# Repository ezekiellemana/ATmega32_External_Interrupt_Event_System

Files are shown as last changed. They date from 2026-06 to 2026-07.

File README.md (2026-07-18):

# ATmega32 External Interrupt Event Counter System

## CT 321 PBL 07 - External Interrupt-Based Emergency Stop and Event Counter System

This repository contains the completed ATmega32 external interrupt emergency stop and event counter system. The project demonstrates event-driven embedded-system control using INT0, INT1, and INT2. The design was verified using SimulIDE, KiCad, MPLAB for VS Code / AVR-GCC compatible firmware, Gerber export, and a recorded demonstration video.

---

## Final Submission Status

| Requirement | Evidence / Location | Status |
| --- | --- | --- |
| System block diagram | `documentation/block_diagram.png` | Complete |
| ATmega32 pin mapping table | `documentation/pin_mapping_table.md` | Complete |
| Firmware flowchart | `documentation/flowchart.png` | Complete |
| KiCad schematic | `kicad/schematic/kicad_schematic.png`, `.pdf`, and `kicad/ATmega32_External_Interrupt_Event_System.kicad_sch` | Complete |
| KiCad PCB layout | `kicad/pcb/kicad_pcb.png` and `kicad/ATmega32_External_Interrupt_Event_System.kicad_pcb` | Complete |
| KiCad PCB 3D view | `kicad/pcb/kicad_pcb_3D.png`, `kicad/pcb/kicad_pcb_3D_2.png` | Complete |
| DRC result | `kicad/pcb/drc_zero_errors.png` | Complete - 0 violations / 0 unconnected items |
| Gerber and drill files | `kicad/gerber/` | Complete |
| Firmware source code | `firmware/src/main.c` | Complete |
| Compiled HEX file | `firmware/hex/emergency_event_counter.hex` | Complete |
| SimulIDE circuit | `simulide/circuit/emergency_event_counter.sim1` | Complete |
| SimulIDE screenshots | `simulide/screenshots/` | Complete - 7 tests captured |
| Test results table | `documentation/test_results.md` | Complete |
| Final report DOCX | `documentation/final_report/CT_321_PBL_07_Group07_Final_Report.docx` | Complete |
| Final report PDF | `documentation/final_report/CT_321_PBL_07_Group07_Final_Report.pdf` | Complete |
| PowerPoint presentation | `documentation/CT_321_PBL_07_Group07_Presentation.pptx` | Complete |
| Demonstration video | `media/demo_video.mp4` | Complete |

---

## Circuit and PCB Images

### Schematic

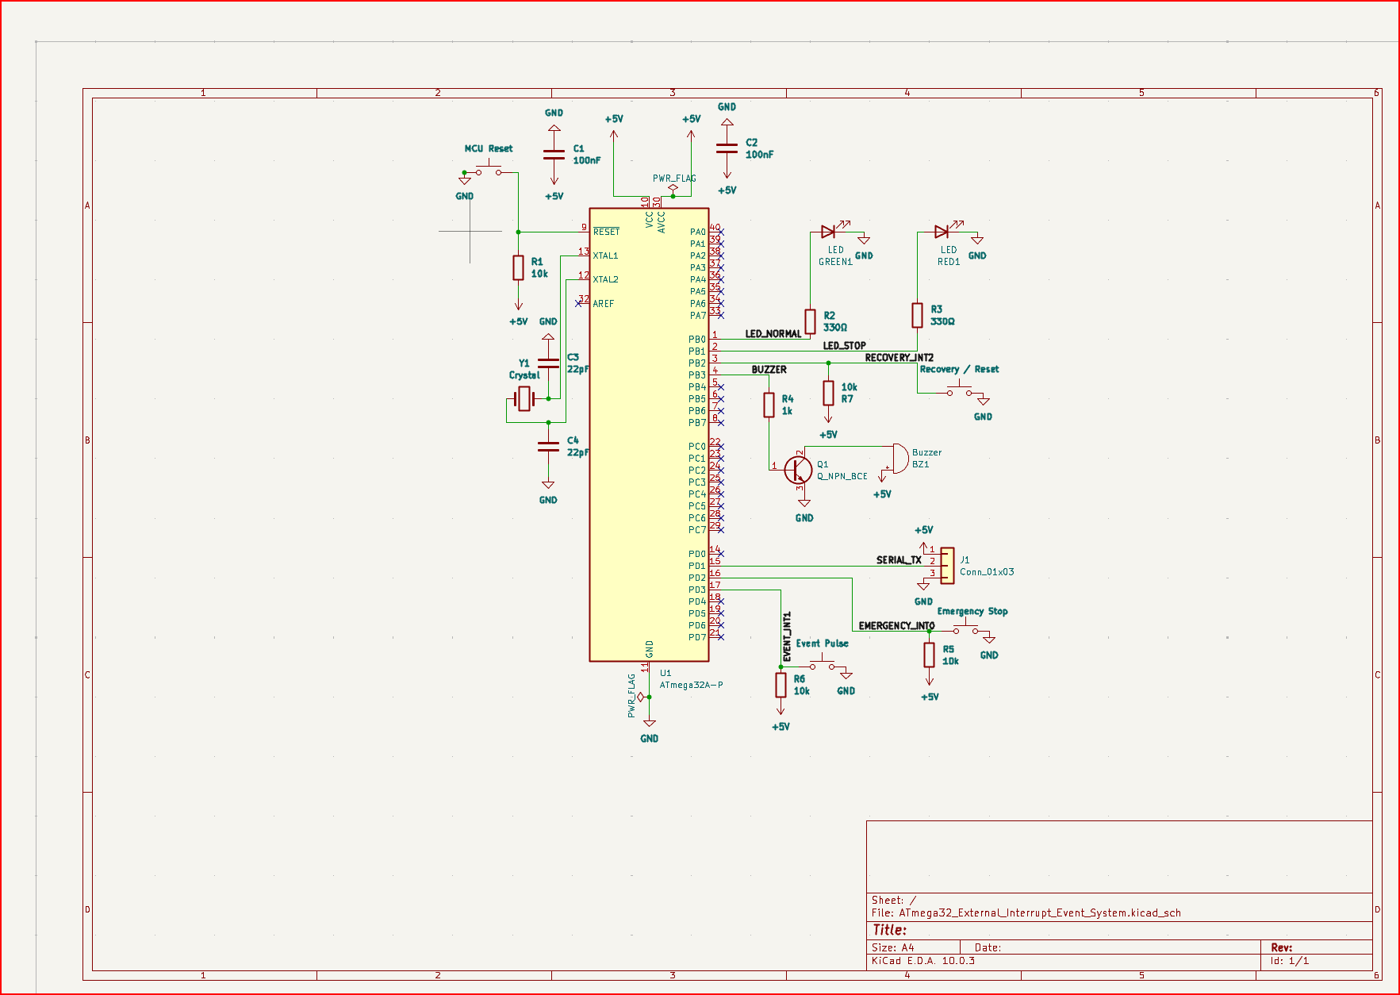
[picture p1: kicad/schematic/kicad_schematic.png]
KiCad schematic


### PCB Layout (2D)

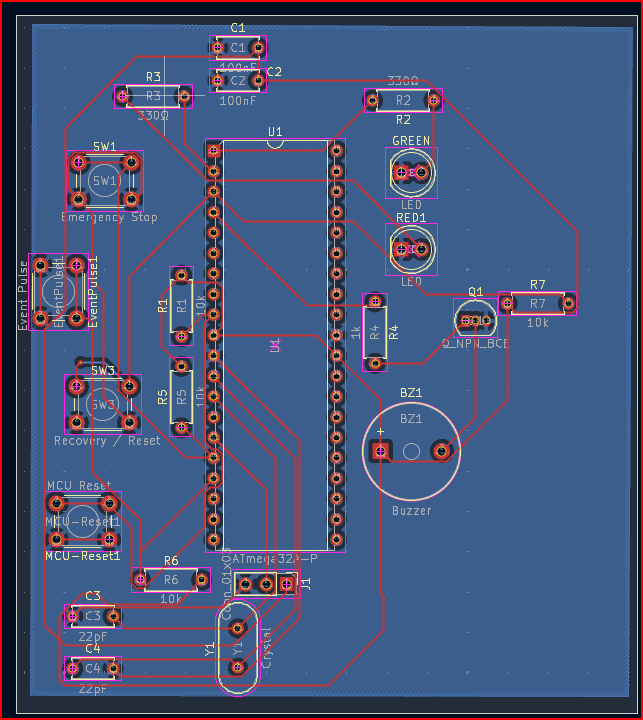
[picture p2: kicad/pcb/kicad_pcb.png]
KiCad PCB layout


### PCB 3D View

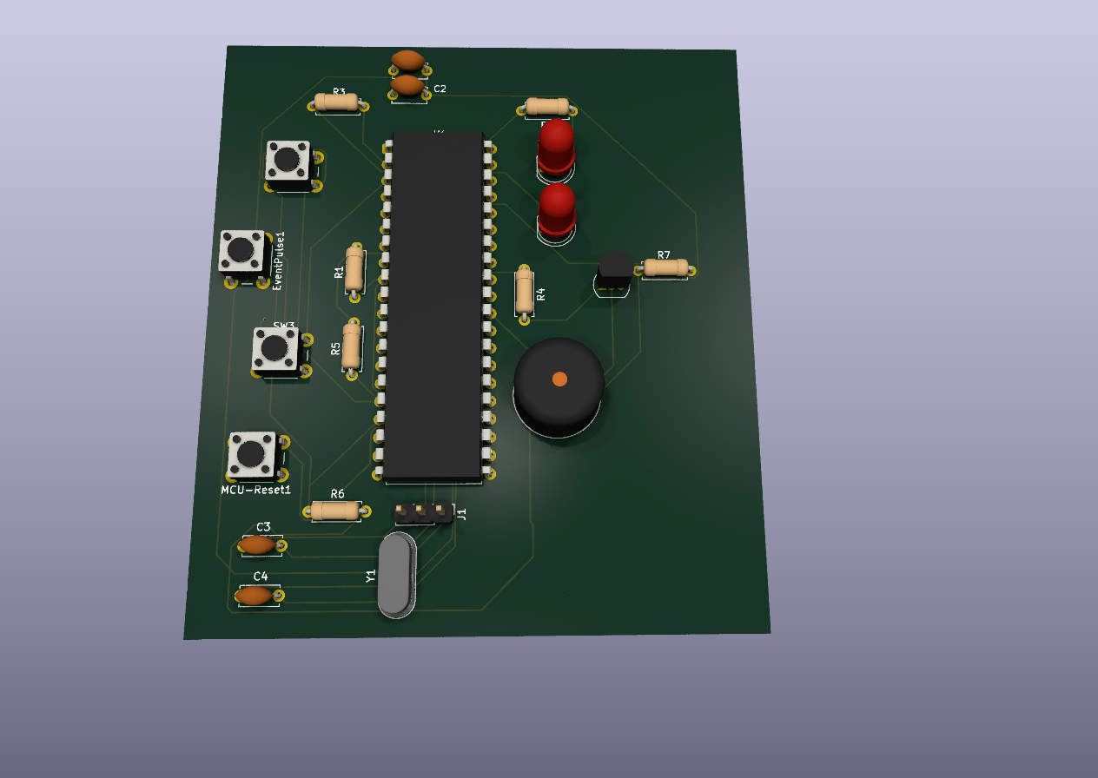
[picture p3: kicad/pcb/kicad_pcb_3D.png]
KiCad PCB 3D view


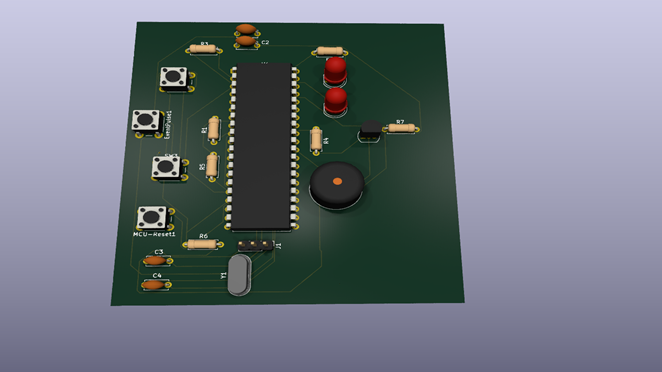
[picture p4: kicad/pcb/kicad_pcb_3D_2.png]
KiCad PCB 3D view - alternate angle


---

## System Behaviour

| Action | Expected Result |
| --- | --- |
| System powered ON | Green LED ON, red LED OFF, buzzer OFF, serial count = 0 |
| Event pulse on INT1 | Event count increases only in normal mode |
| Emergency stop on INT0 | Red LED and buzzer ON, green LED OFF, counting stops |
| Event during emergency | Count does not increase |
| Recovery on INT2 during emergency | System returns to normal mode and keeps the current count |
| Recovery/reset on INT2 during normal mode | Event count resets to zero |

---

## Important Simulation Settings

```text
MCU: ATmega32 / ATmega32A
Clock: 8 MHz
HEX file: firmware/hex/emergency_event_counter.hex
UART: 9600 baud, 8 data bits, 1 stop bit
Inputs: active LOW buttons with pull-ups
RESET: held HIGH during normal running
```

---

## Folder Structure

```text
ATmega32_External_Interrupt_Event_System/
|-- README.md
|-- firmware/
|   |-- src/main.c
|   |-- include/
|   `-- hex/emergency_event_counter.hex
|-- kicad/
|   |-- ATmega32_External_Interrupt_Event_System.kicad_pro
|   |-- ATmega32_External_Interrupt_Event_System.kicad_sch
|   |-- ATmega32_External_Interrupt_Event_System.kicad_pcb
|   |-- schematic/
|   |-- pcb/
|   `-- gerber/
|-- simulide/
|   |-- circuit/emergency_event_counter.sim1
|   `-- screenshots/
|-- documentation/
|   |-- CT_321_PBL_07_Group07_Presentation.pptx
|   |-- block_diagram.png
|   |-- flowchart.png
|   |-- interrupt_configuration.md
|   |-- pin_mapping_table.md
|   |-- test_results.md
|   `-- final_report/
|       |-- CT_321_PBL_07_Group07_Final_Report.docx
|       `-- CT_321_PBL_07_Group07_Final_Report.pdf
`-- media/
    |-- demo_video.mp4
    `-- demonstration_video_link.txt
```

---

## Demonstration Summary

The final simulation and video demonstrate normal startup, single event counting, multiple event counting, emergency stop, lockout of event counting during emergency mode, recovery back to normal mode, and reset of the count in normal mode.

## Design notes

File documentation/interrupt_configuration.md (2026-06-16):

# Interrupt Configuration

## Button Wiring — Active-LOW Inputs

The emergency, event, and recovery/reset buttons are wired as active-LOW inputs. Each button connects the microcontroller input pin to GND when pressed.

When the button is not pressed, the input pin is held HIGH. When the button is pressed, the input pin goes LOW. This HIGH-to-LOW transition creates the falling edge used to trigger the external interrupt.

The firmware enables the ATmega32 internal pull-up resistors. The KiCad schematic and PCB also include external 10 kΩ pull-up resistors for the interrupt inputs. This is acceptable because the external pull-ups reinforce the HIGH level and make the schematic clear for the assignment.

---

## Interrupt Inputs

| Interrupt | MCU Pin | Net Label | Button | Pull-up |
| --- | --- | --- | --- | --- |
| INT0 | PD2 / DIP pin 16 | `EMERGENCY_INT0` | Emergency stop | 10 kΩ to +5V plus internal pull-up |
| INT1 | PD3 / DIP pin 17 | `EVENT_INT1` | Event pulse | 10 kΩ to +5V plus internal pull-up |
| INT2 | PB2 / DIP pin 3 | `RECOVERY_INT2` | Recovery/reset | 10 kΩ to +5V plus internal pull-up |

---

## Falling-Edge Trigger Configuration

### INT0 — Emergency Stop

INT0 uses PD2 and is configured for falling edge triggering.

```c
MCUCR |=  (1 << ISC01);
MCUCR &= ~(1 << ISC00);
```

### INT1 — Event Pulse

INT1 uses PD3 and is also configured for falling edge triggering.

```c
MCUCR |=  (1 << ISC11);
MCUCR &= ~(1 << ISC10);
```

### INT2 — Recovery / Reset

INT2 uses PB2. On ATmega32, INT2 uses the ISC2 bit in MCUCSR. Clearing ISC2 selects falling edge triggering.

```c
MCUCSR &= ~(1 << ISC2);
```

All interrupts are enabled through GICR:

```c
GICR |= (1 << INT0) | (1 << INT1) | (1 << INT2);
```

---

## ISR Behaviour

| Interrupt | Trigger | Firmware action |
| --- | --- | --- |
| INT0 emergency | Emergency button pressed | Sets `emergency_mode = 1`; red LED and buzzer turn ON; counting is locked |
| INT1 event | Event button/sensor pulse | Increments `event_count` only if `emergency_mode == 0` |
| INT2 recovery/reset | Recovery button pressed | If in emergency mode, returns to normal; if already normal, resets count to 0 |

---

## Debounce Logic

Mechanical push buttons can bounce and create several fast transitions during one press. The firmware prevents false multiple counts using a Timer0 millisecond tick and a 200 ms debounce window.

Timer0 creates a 1 ms system tick:

```text
Clock: 8 MHz
Prescaler: 64
OCR0: 124
Tick: 1 ms
```

Each external interrupt has its own last-accepted timestamp. An interrupt is accepted only when at least 200 ms has passed since the previous accepted interrupt on the same line.

```c
if ((now - last_int0_ms) >= DEBOUNCE_MS) {
    last_int0_ms = now;
    emergency_mode = 1;
}
```

This prevents button bounce from producing multiple counts or repeated emergency/recovery actions.

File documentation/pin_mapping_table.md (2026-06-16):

# ATmega32 Pin Mapping Table

| ATmega32 Pin | DIP-40 Pin # | Direction | Net Label | Connected Device | Notes |
| --- | --- | --- | --- | --- | --- |
| PB0 | 1 | Output | `LED_NORMAL` | R2 330 Ω → Green LED → GND | HIGH = normal LED ON |
| PB1 | 2 | Output | `LED_STOP` | R3 330 Ω → Red LED → GND | HIGH = stop LED ON |
| PB2 / INT2 | 3 | Input | `RECOVERY_INT2` | SW3 → GND, R7 10 kΩ → +5V | Recovery/reset interrupt |
| PB3 | 4 | Output | `BUZZER` | R4 1 kΩ → Q1 base → BZ1 driver | HIGH = buzzer ON |
| RESET | 9 | Input | `RESET` | R1 10 kΩ → +5V, reset button → GND | Active-LOW MCU reset |
| VCC | 10 | Power | `+5V` | +5V zone, C1 100 nF to GND | Digital supply |
| GND | 11 | Power | `GND` | GND zone | Ground |
| XTAL1 | 13 | Input | `XTAL1` | Y1 8 MHz crystal, C3 22 pF to GND | Clock input |
| XTAL2 | 14 | Output | `XTAL2` | Y1 8 MHz crystal, C4 22 pF to GND | Clock output |
| PD1 / TXD | 15 | Output | `SERIAL_TX` | J1 pin 2 | UART transmit, 9600 baud |
| PD2 / INT0 | 16 | Input | `EMERGENCY_INT0` | SW1 → GND, R5 10 kΩ → +5V | Emergency stop interrupt |
| PD3 / INT1 | 17 | Input | `EVENT_INT1` | SW2 → GND, R6 10 kΩ → +5V | Event pulse interrupt |
| AVCC | 30 | Power | `+5V` | +5V zone, C2 100 nF to GND | Must be tied to VCC |
| GND | 31 | Power | `GND` | GND zone | Ground |

## Unused Pins

The remaining ATmega32 pins are not used in this project. They are marked as no-connect in the schematic where appropriate.

## Power Notes

- VCC and AVCC are both connected to +5V.
- Both GND pins are connected to the GND zone.
- C1 and C2 are 100 nF decoupling capacitors.
- A B.Cu copper zone is used for GND.
- An F.Cu copper zone is used for +5V.

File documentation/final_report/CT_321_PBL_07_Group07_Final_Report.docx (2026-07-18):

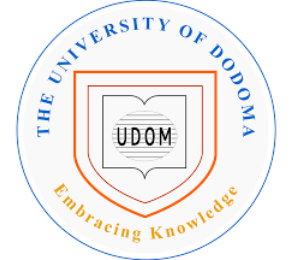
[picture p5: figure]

THE UNIVERSITY OF DODOMA

COLLEGE OF INFORMATICS AND VIRTUAL EDUCATION

DEPARTMENT OF COMPUTER SCIENCE AND ENGINEERING

GROUP ASSIGNMENT REPORT

GROUP NUMBER: 07
MODULE NAME: MICROCONTROLLER SYSTEMS
MODULE CODE: CT 321
SEMESTER: TWO
ACADEMIC YEAR: 2025 / 2026

PBL TITLE: EXTERNAL INTERRUPT-BASED EMERGENCY STOP AND EVENT COUNTER SYSTEM

PARTICIPANTS

S/N | NAME | REG NUMBER | PROGRAMME
1 | EZEKIEL LEMANA | T23-03-00241 | CE3
2 | HARUN KADILO | T23-03-01251 | CE3
3 | JACKSON MANDA | T23-03-18278 | CE3
4 | YASSIN JABIR | T23-03-14605 | CE3

# 1. Introduction

Many embedded systems must react immediately to external events such as emergency stop buttons, object detection sensors, alarms, or motion triggers. A polling-based program may miss short input pulses if the processor is busy with another task. External interrupts solve this problem by allowing the microcontroller to stop normal execution temporarily and run a service routine when an important event occurs.

This project demonstrates how ATmega32 external interrupts can be used to build a safe event-driven system. The system counts external event pulses in normal mode, enters emergency-stop mode when the emergency button is pressed, prevents counting during emergency mode, and returns to normal operation using a recovery/reset button.

# 2. Problem Statement and Objectives

The problem is to design a controller that can count normal events while still responding immediately to an emergency condition. The emergency input must dominate the normal counting operation so that the system stops counting and activates alarm indicators without delay.

## 2.1 Objectives

- To design an ATmega32-based event counter using external interrupts.
- To implement immediate emergency-stop response using INT0.
- To count event pulses during normal mode using INT1.
- To recover from emergency mode and reset the count using INT2.
- To indicate system state using green LED, red LED, buzzer, and UART serial output.
- To design the schematic and PCB layout in KiCad and generate Gerber files.
- To verify the system using SimulIDE screenshots and a demonstration video.

# 3. Expected System Operation

Input / Event | Expected Response
System powered ON | Green LED ON, red LED OFF, buzzer OFF, serial shows NORMAL mode with count 0.
Object/event pulse detected | Event count increases only when the system is in normal mode.
Emergency stop button pressed | System enters EMERGENCY STOP mode; red LED and buzzer turn ON; counting stops.
Event pulse during emergency | Event count does not increase.
Recovery button pressed during emergency | System returns to NORMAL mode and keeps the current count.
Recovery/reset button pressed in normal mode | Event count resets to zero.

# 4. System Design

## 4.1 System Block Diagram

The block diagram shows the external interrupt inputs, ATmega32 controller, output indicators, buzzer, serial terminal, and 5 V power supply used in the system.

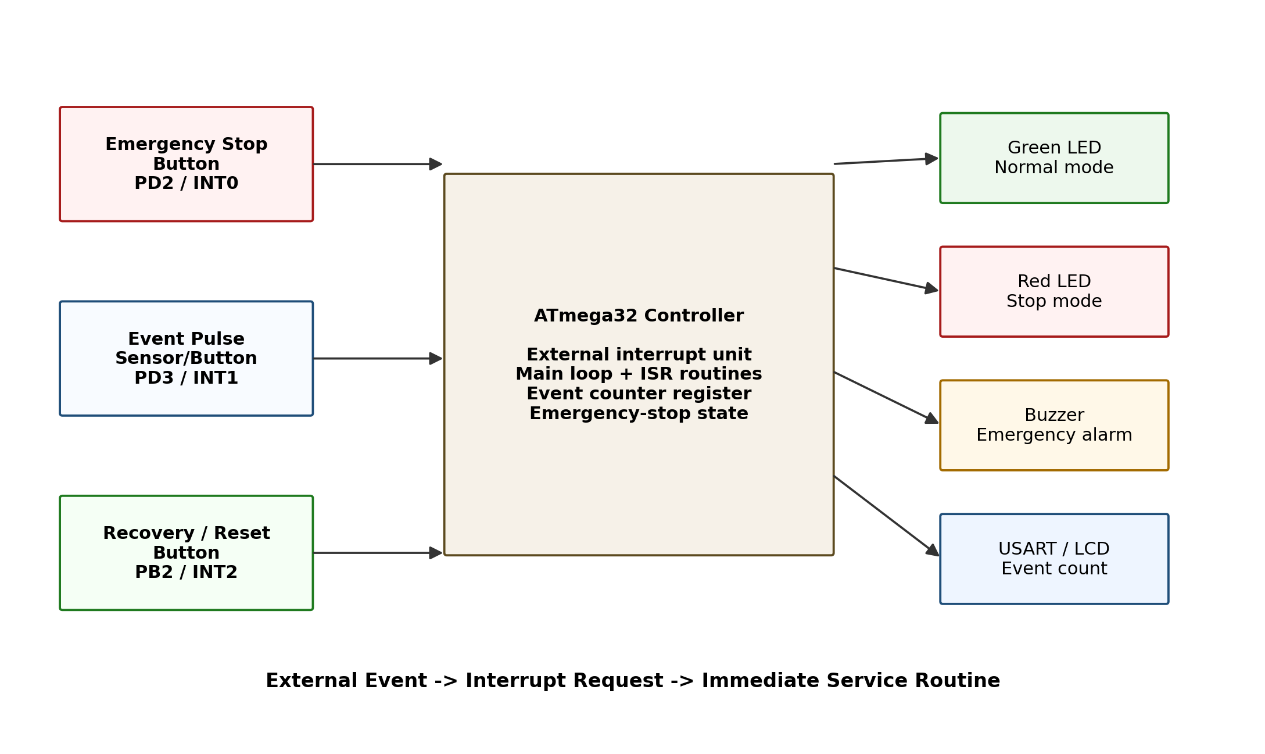
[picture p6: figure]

Figure 1: System block diagram.

## 4.2 Components Used

Component | Quantity | Purpose
ATmega32 / ATmega32A | 1 | Main microcontroller and interrupt controller.
Emergency stop push button | 1 | Triggers INT0 and starts emergency mode.
Event pulse button / sensor | 1 | Triggers INT1 and increments the event count.
Recovery/reset push button | 1 | Triggers INT2; recovers from emergency or resets count.
MCU reset button | 1 | Hardware reset for the ATmega32.
Green LED | 1 | Normal mode indicator.
Red LED | 1 | Emergency stop indicator.
Active buzzer | 1 | Emergency alarm output.
NPN transistor and 1 kOhm resistor | 1 set | Buzzer driver stage.
330 Ohm resistors | 2 | LED current limiting.
10 kOhm resistors | 4 | RESET and interrupt input pull-up resistors.
8 MHz crystal and 22 pF capacitors | 1 set | External clock circuit.
100 nF capacitors | 2 | VCC and AVCC decoupling.
3-pin serial header | 1 | +5V, serial TX, and GND connection.

## 4.3 ATmega32 Pin Mapping

ATmega32 Pin | DIP Pin | Direction | Net / Function | Connected Device
PB0 | 1 | Output | LED_NORMAL | R2 330 Ohm -> Green LED -> GND
PB1 | 2 | Output | LED_STOP | R3 330 Ohm -> Red LED -> GND
PB2 / INT2 | 3 | Input | RECOVERY_INT2 | SW3 -> GND, R7 10 kOhm -> +5V
PB3 | 4 | Output | BUZZER | R4 1 kOhm -> Q1 base -> Buzzer driver
RESET | 9 | Input | RESET | R1 10 kOhm -> +5V, reset button -> GND
VCC | 10 | Power | +5V | Digital supply and decoupling
GND | 11 | Power | GND | Ground zone
XTAL1 | 13 | Input | XTAL1 | 8 MHz crystal and C3 22 pF
XTAL2 | 14 | Output | XTAL2 | 8 MHz crystal and C4 22 pF
PD1 / TXD | 15 | Output | SERIAL_TX | J1 pin 2, UART 9600 baud
PD2 / INT0 | 16 | Input | EMERGENCY_INT0 | SW1 -> GND, R5 10 kOhm -> +5V
PD3 / INT1 | 17 | Input | EVENT_INT1 | SW2 -> GND, R6 10 kOhm -> +5V
AVCC | 30 | Power | +5V | Analog/digital supply and decoupling
GND | 31 | Power | GND | Ground zone

# 5. Interrupt and Firmware Design

## 5.1 Interrupt Configuration

The input buttons are wired as active-LOW inputs. The inputs are normally HIGH through pull-up resistors and become LOW when a button is pressed. Therefore, falling-edge triggering is used for INT0, INT1, and INT2.

Interrupt | MCU Pin | Trigger | Firmware Action
INT0 | PD2 | Falling edge | Set emergency_mode = 1; red LED and buzzer ON; counting locked.
INT1 | PD3 | Falling edge | Increment event_count only if emergency_mode == 0.
INT2 | PB2 | Falling edge | If emergency, recover to normal; if normal, reset count to 0.

## 5.2 Firmware Flowchart

The firmware initializes GPIO, UART, Timer0, and the three external interrupts. The main loop updates outputs and serial messages, while the ISRs handle urgent events.

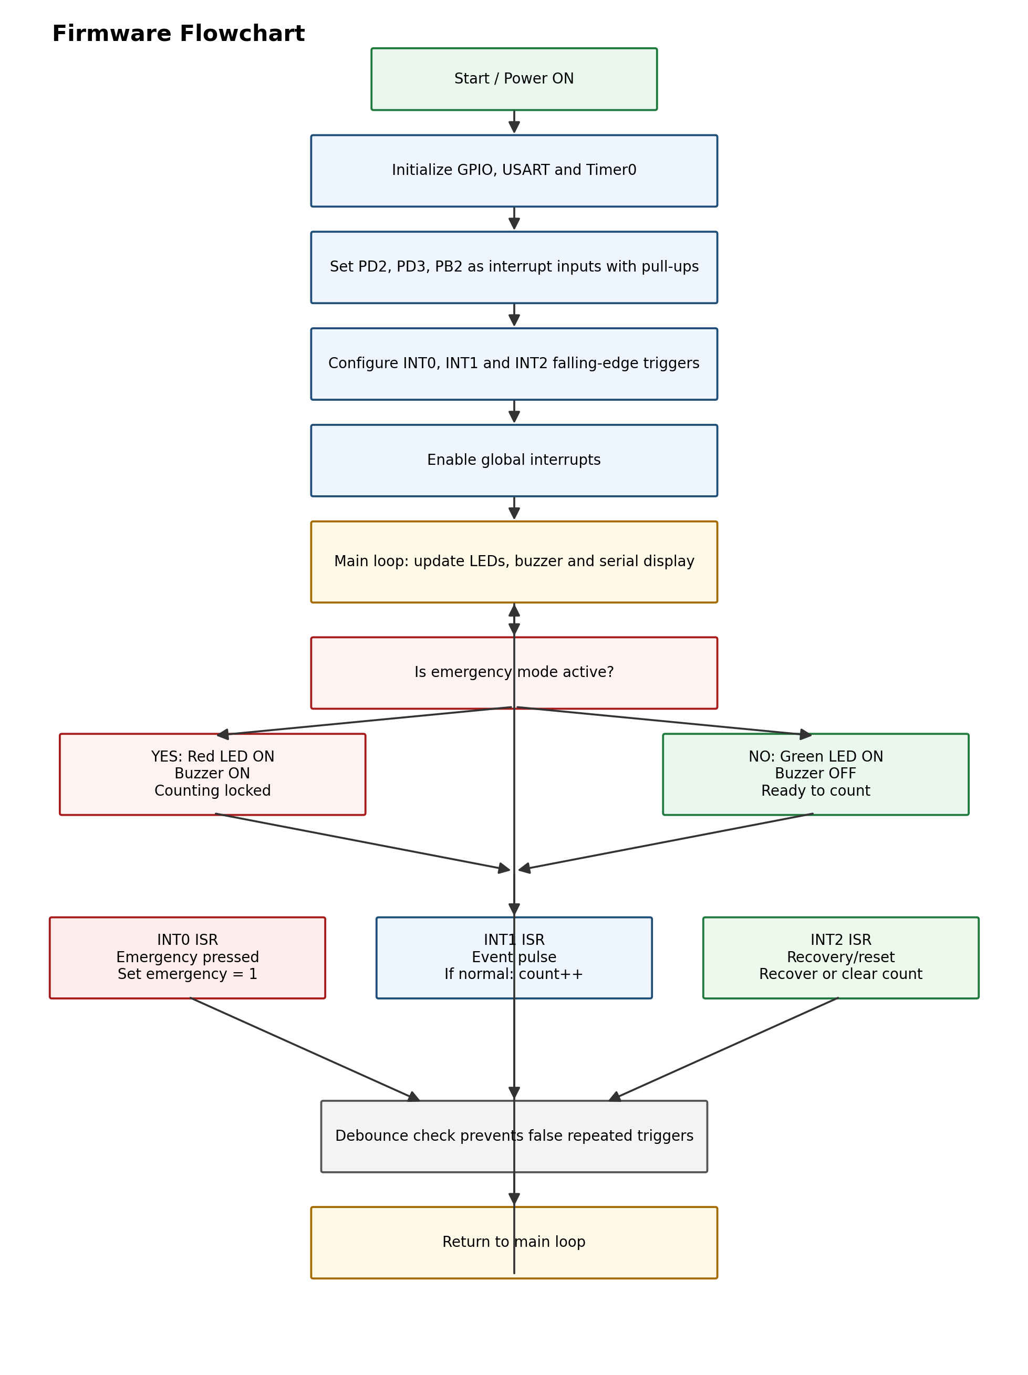
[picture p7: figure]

Figure 2: Firmware flowchart.

## 5.3 Key Firmware Logic

Timer0 generates a 1 ms system tick. A 200 ms debounce window is applied separately to each external interrupt to prevent false multiple triggers caused by mechanical button bounce.

#define DEBOUNCE_MS 200UL
#define HEARTBEAT_MS 1000UL

INT0: emergency stop
INT1: event count only in normal mode
INT2: recovery/reset

## 5.4 Interrupt Service Routine Summary

ISR(INT0_vect) -> emergency_mode = 1;
ISR(INT1_vect) -> if (!emergency_mode) event_count++;
ISR(INT2_vect) -> if emergency: emergency_mode = 0; else: event_count = 0;

The final compiled HEX file used in simulation is `firmware/hex/emergency_event_counter.hex`. The verified build used an 8 MHz clock and produced approximately 1403 bytes of flash use and 80 bytes of SRAM use.

# 6. KiCad Schematic and PCB Design


Figure 3: Final KiCad schematic.

## PCB Layout

The PCB layout was routed using KiCad. A B.Cu copper zone was used for GND and an F.Cu copper zone was used for +5V. Interrupt input traces, output traces, and the serial header are labelled through the schematic net names.


Figure 4: Final KiCad PCB layout.

## Design Rule Check and Gerber Output

The final PCB passed KiCad DRC with zero violations, zero unconnected items, zero errors, and zero warnings. Gerber and drill files were exported and stored in `kicad/gerber/`.

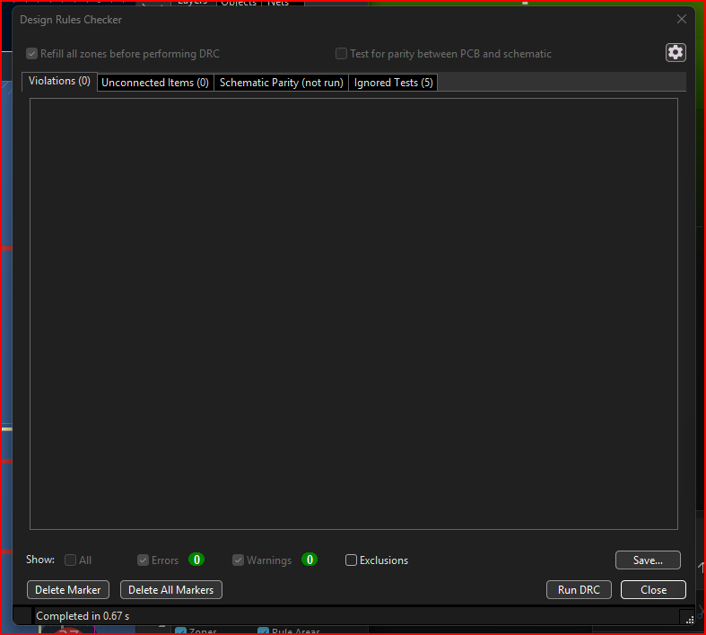
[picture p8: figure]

Figure 5: KiCad DRC result showing zero violations and zero unconnected items.

Gerber / Drill Output | Location
Front copper | kicad/gerber/*-F_Cu.gbr
Back copper | kicad/gerber/*-B_Cu.gbr
Solder mask and silkscreen | kicad/gerber/*-Mask.gbr and *-Silkscreen.gbr
Board outline | kicad/gerber/*-Edge_Cuts.gbr
Drill files | kicad/gerber/*-PTH.drl and *-NPTH.drl
Gerber zip | kicad/gerber/ATmega32_Gerber_Files.zip

## PCB 3D-VIEW

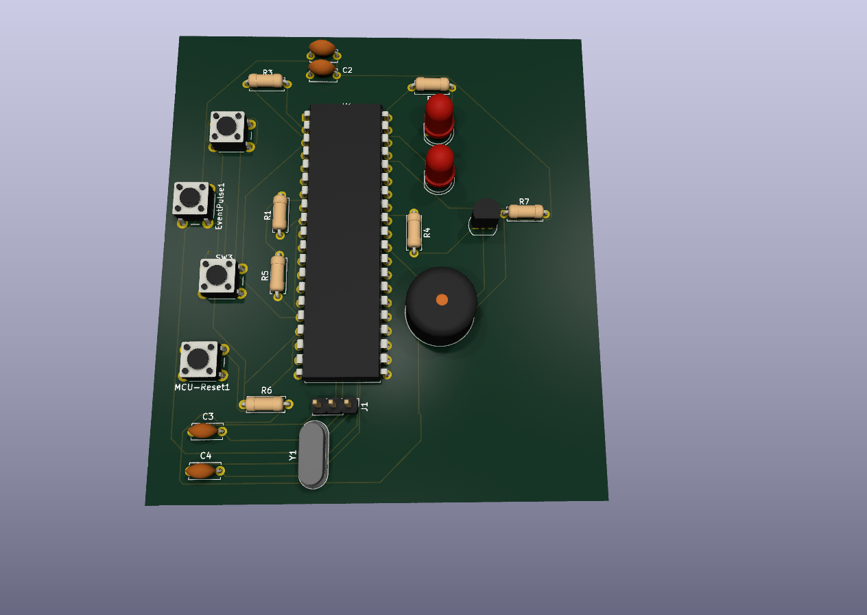
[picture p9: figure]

## 7. Simulation Screenshot Summary

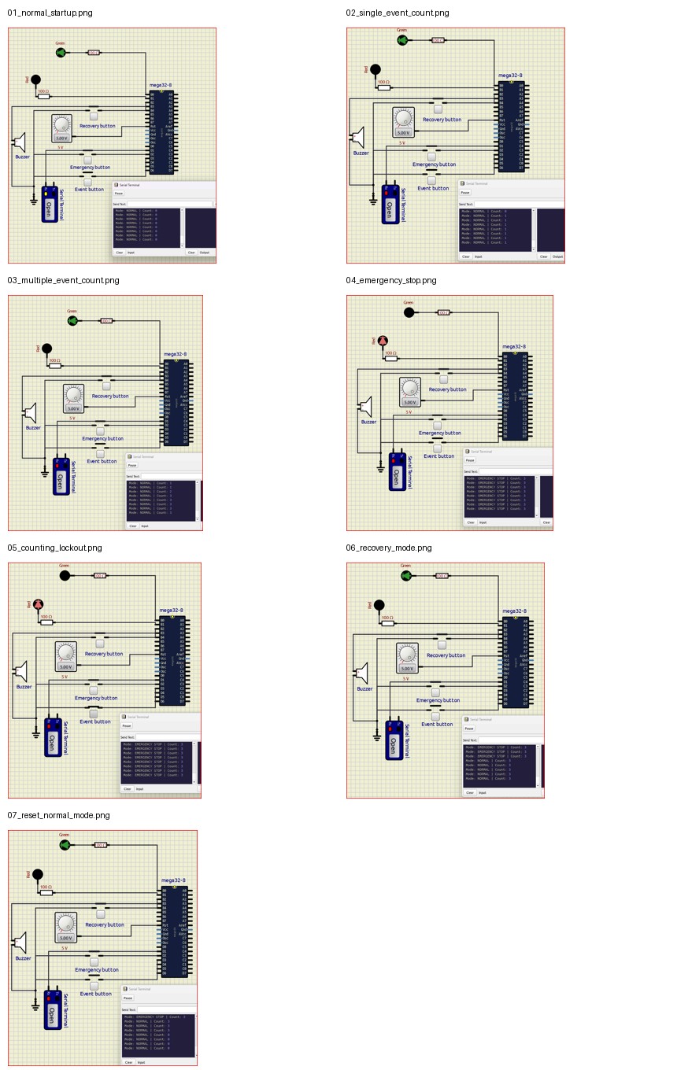
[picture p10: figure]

Figure 6: Contact sheet of all SimulIDE test screenshots.

# 8. Test Results

No. | Test Case | Expected Output | Observed Output | Result
1 | Normal startup | Green LED ON, red LED OFF, buzzer OFF, count 0. | System starts in NORMAL mode and serial output shows count 0. | PASS
2 | Single event pulse | One event pulse increments count to 1. | Serial output shows NORMAL mode with count 1. | PASS
3 | Multiple event pulses | Repeated events increase count step by step. | Count increases correctly after multiple event button presses. | PASS
4 | Emergency stop | Red LED and buzzer ON; counting stops. | System enters EMERGENCY STOP mode and alarm output is activated. | PASS
5 | Event during emergency | Count must not increase. | Count remains unchanged while emergency mode is active. | PASS
6 | Recovery mode | System returns to NORMAL mode and preserves count. | Serial output returns to NORMAL mode with previous count retained. | PASS
7 | Reset in normal mode | Pressing recovery/reset in normal mode resets count to 0. | Serial output shows NORMAL mode with count 0. | PASS

## 8.1 Individual Simulation Evidence

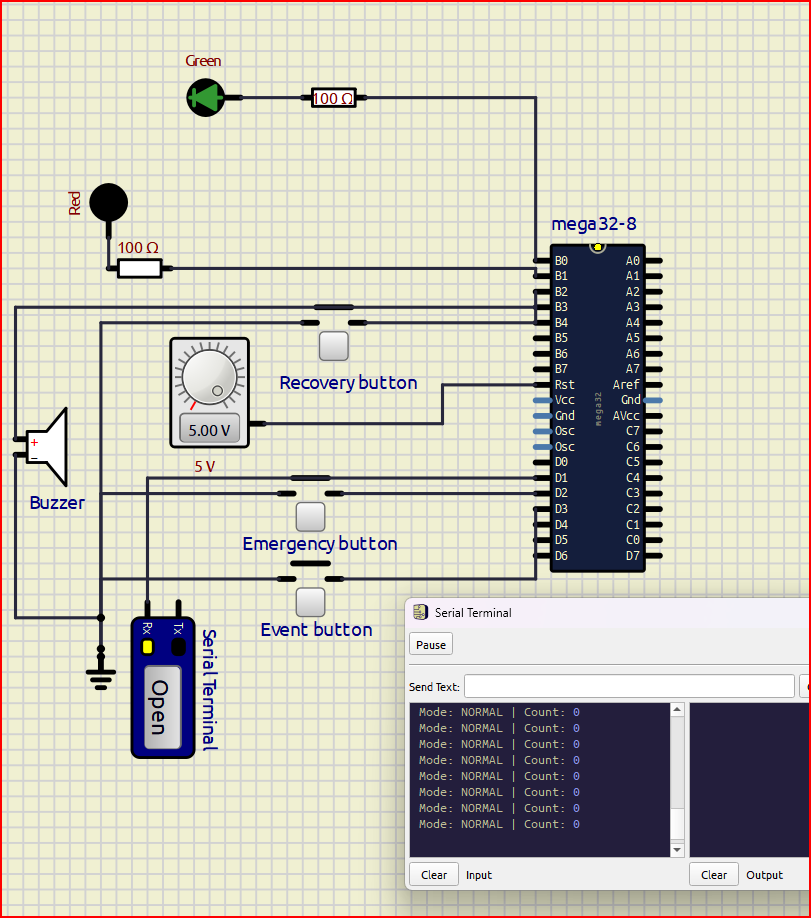
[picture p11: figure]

Figure 7: Normal startup - green LED ON and count 0.

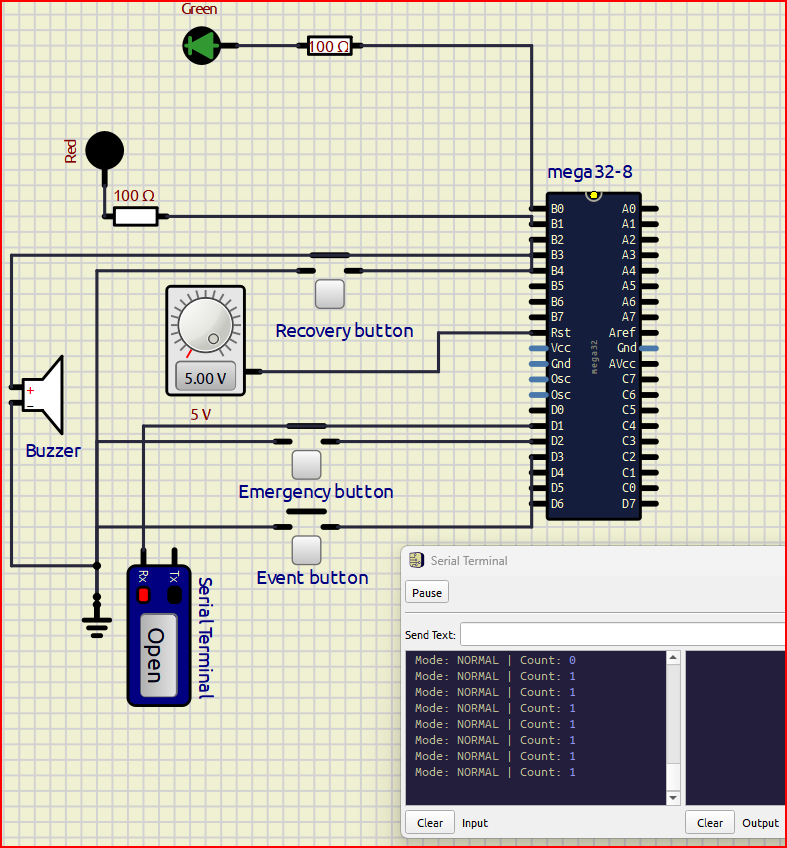
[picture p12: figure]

Figure 8: Single event pulse - count increases to 1.

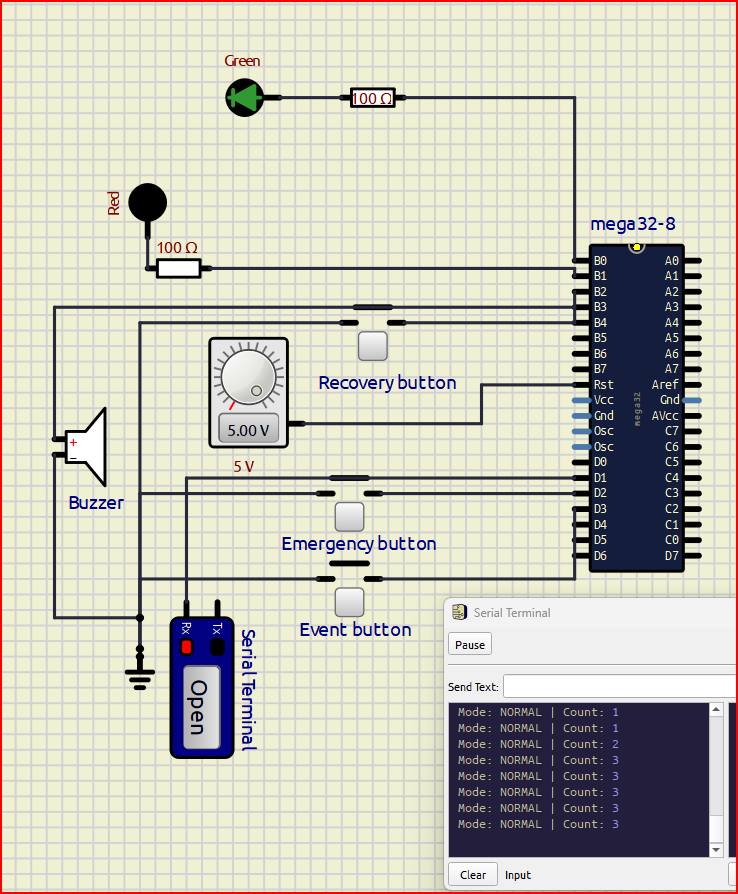
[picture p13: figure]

Figure 9: Multiple event pulses - count increases correctly.

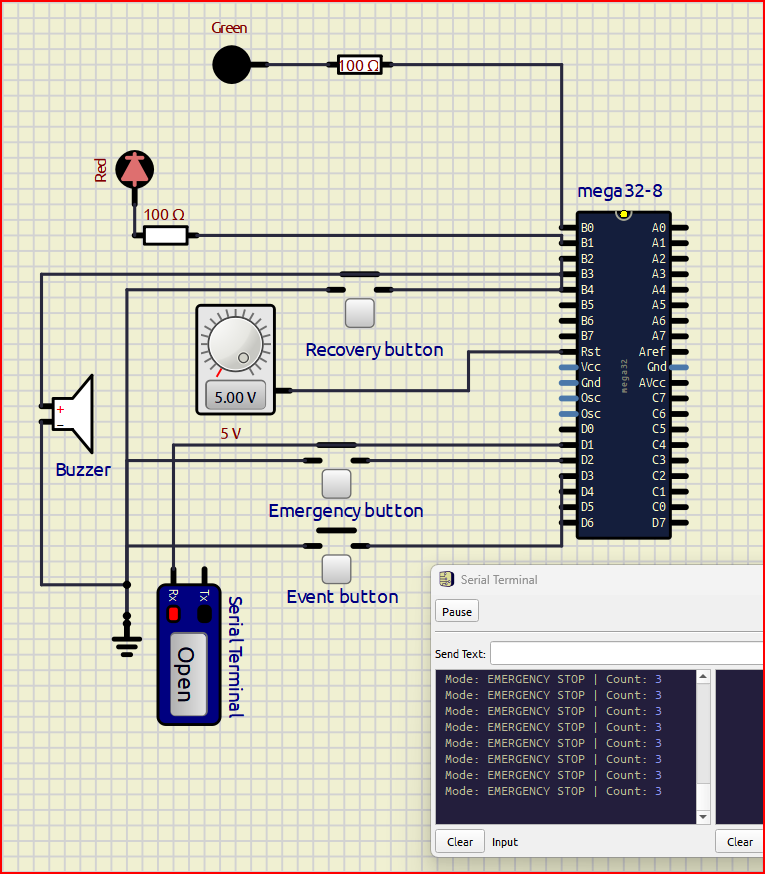
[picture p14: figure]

Figure 10: Emergency stop - emergency mode active.

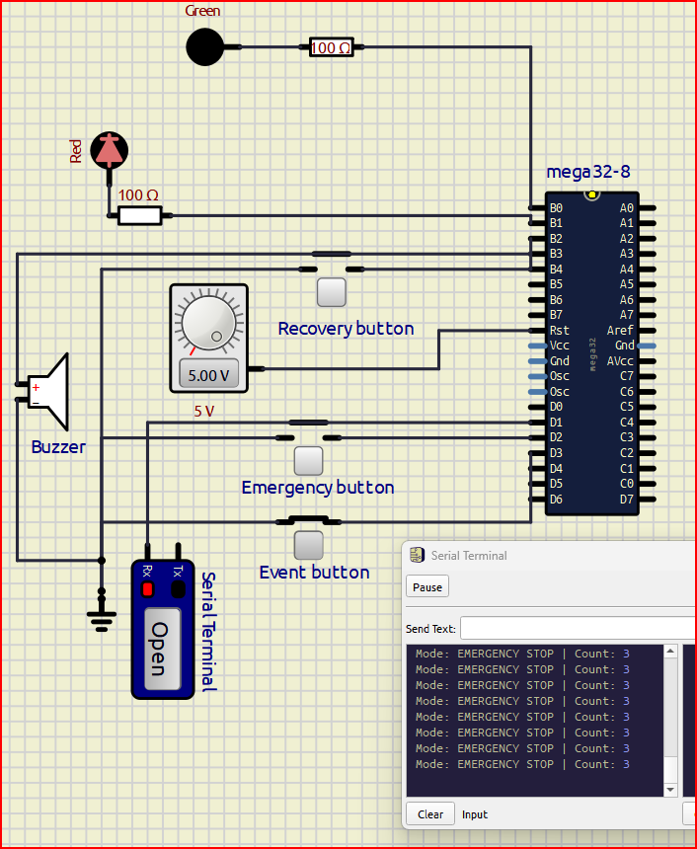
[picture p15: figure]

Figure 11: Event during emergency - count remains locked.

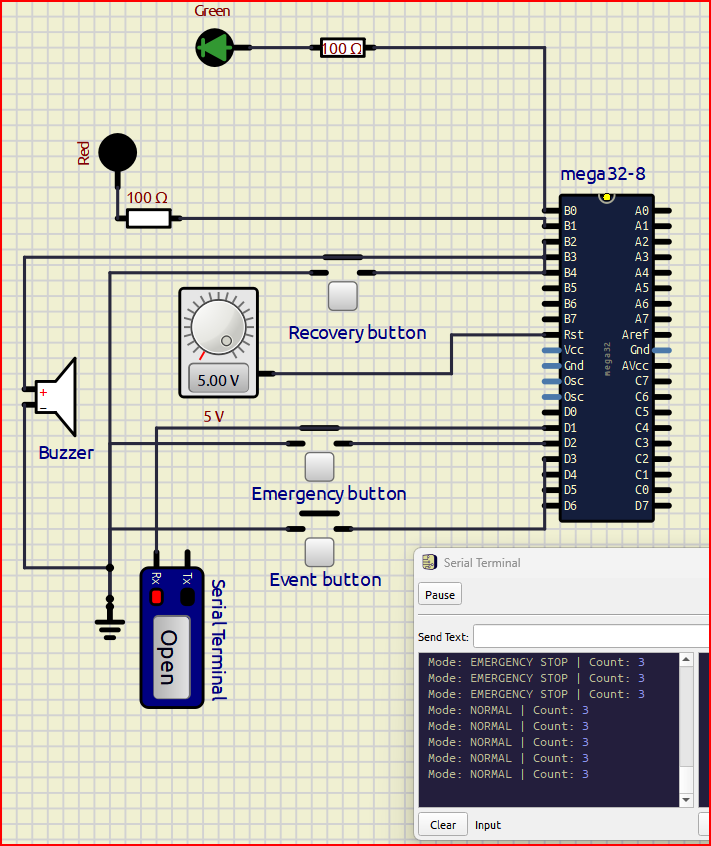
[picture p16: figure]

Figure 12: Recovery mode - system returns to normal mode.

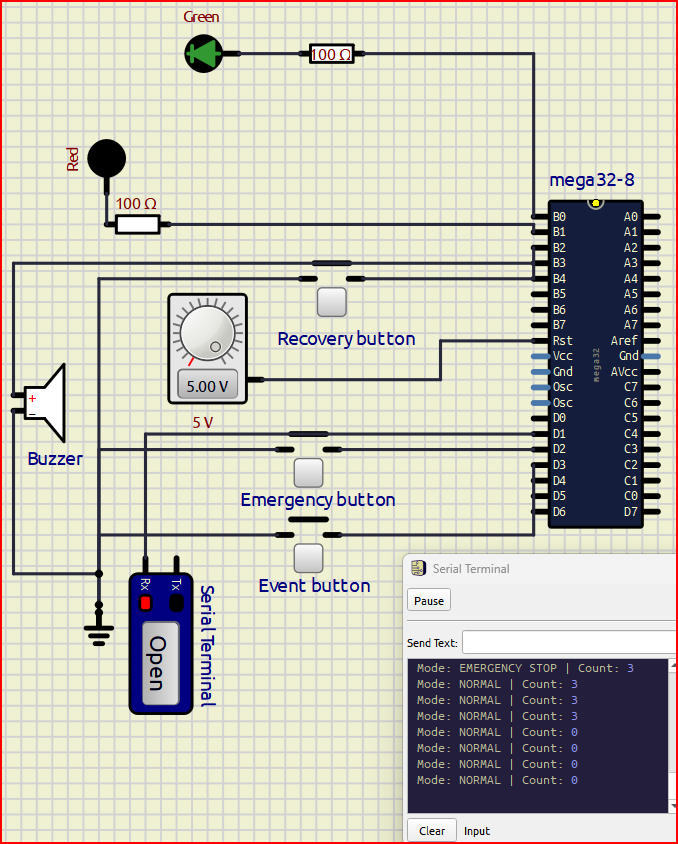
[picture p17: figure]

Figure 13: Reset in normal mode - count resets to 0.

# 9. Challenges and Solutions

Challenge | Solution
RESET pin issue in SimulIDE | The RESET pin was held HIGH using a 5 V source so the firmware could run normally.
Mechanical button bounce | Timer0 was used to create a 1 ms tick and each interrupt line uses a 200 ms debounce window.
Many GND and +5V connections on the PCB | Copper zones were used: B.Cu for GND and F.Cu for +5V.
PCB routing unconnected items | KiCad DRC was used to locate and fix each missing connection until DRC showed 0 violations.
Emergency and reset button behavior | INT2 was designed with dual behavior: recover during emergency, reset count when already in normal mode.

# 10. Repository and File Organization

ATmega32_External_Interrupt_Event_System/
├── README.md
├── firmware/
│ ├── src/main.c
│ └── hex/emergency_event_counter.hex
├── kicad/
│ ├── ATmega32_External_Interrupt_Event_System/
│ ├── schematic/
│ ├── pcb/
│ └── gerber/
├── simulide/
│ ├── circuit/emergency_event_counter.sim1
│ └── screenshots/
├── documentation/
│ ├── block_diagram.png
│ ├── firmware_flowchart.png
│ ├── interrupt_configuration.md
│ ├── pin_mapping_table.md
│ ├── test_results.md
│ └── final_report/
└── media/
└── demo_video.mp4

# 11. Conclusion

The project successfully demonstrates an ATmega32 external interrupt system for emergency stop and event counting. INT0 handles the emergency stop, INT1 handles event pulse counting, and INT2 handles recovery/reset. The system correctly locks event counting during emergency mode and returns to normal operation after recovery. The implementation also includes debounce handling, UART status display, LED and buzzer outputs, KiCad schematic and PCB design, Gerber export, SimulIDE screenshots, and a demonstration video.

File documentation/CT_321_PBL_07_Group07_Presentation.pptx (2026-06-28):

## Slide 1

External Interrupt-Based Emergency Stop
and Event Counter System

ATmega32 Microcontroller | CT 321 PBL 07 | Project 7

Group 7

Department of Computer Engineering

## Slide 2

Problem Statement & Objective

Problem Statement

• Embedded systems must respond immediately to events such as emergency stops, sensor pulses, and alarms.
• Polling can miss short input pulses when the program is busy with another task.
• External interrupts let the ATmega32 pause normal execution and respond the instant an event occurs.

Project Objective

• Design and implement an interrupt-based emergency stop and event counter system using the ATmega32.
• Count external events during normal operation using INT1.
• Enter emergency-stop mode immediately when the emergency button (INT0) is pressed.
• Recover back to normal mode using a dedicated recovery interrupt (INT2).

CT 321 PBL 07 - Group 7 - ATmega32 External Interrupt Event Counter System

2

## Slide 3

Expected System Operation

Two operating modes: NORMAL and EMERGENCY-STOP

Input / Event | Expected System Response
System powered ON | Green LED ON - normal mode
Event pulse detected (INT1) | Event count increases
Recovery / reset button (INT2), normal mode | Event count resets to zero
Emergency stop button (INT0) | Red LED ON, buzzer ON, counting stops
Recovery button (INT2), emergency mode | Buzzer OFF, system returns to normal mode

CT 321 PBL 07 - Group 7 - ATmega32 External Interrupt Event Counter System

3

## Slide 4

Main Hardware Components

Inputs

• ATmega32 microcontroller (8 MHz)
• Emergency stop push button - INT0
• Event pulse push button - INT1
• Recovery / reset push button - INT2
• Green LED - normal mode indicator

Outputs & Support

• Red LED - emergency-stop indicator
• Buzzer - emergency alarm (transistor driver)
• 10 kΩ pull-up resistors on interrupt inputs
• 330 Ω current-limiting resistors for LEDs
• Serial / USART terminal for event count display

CT 321 PBL 07 - Group 7 - ATmega32 External Interrupt Event Counter System

4

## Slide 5

ATmega32 Pin Mapping

ATmega32 Pin | Function | Connected Device
PD2 / INT0 | External Interrupt 0 | Emergency stop button
PD3 / INT1 | External Interrupt 1 | Event pulse button / sensor
PB2 / INT2 | External Interrupt 2 | Recovery / reset button
PB0 | Digital Output | Green LED (normal mode)
PB1 | Digital Output | Red LED (emergency mode)
PB3 | Digital Output | Buzzer
PD1 / TXD | USART Transmit | Event count to serial terminal

CT 321 PBL 07 - Group 7 - ATmega32 External Interrupt Event Counter System

5

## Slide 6

Interrupt Configuration

Trigger Mode

• All three interrupts (INT0, INT1, INT2) are configured for falling-edge triggering.
• Buttons are active-LOW: pin is HIGH when released, goes LOW when pressed.

Debounce Logic

• Timer0 generates a 1 ms system tick (8 MHz clock, prescaler 64, OCR0 = 124).
• Each interrupt line tracks its own last-accepted timestamp.
• An interrupt is accepted only if at least 200 ms passed since the previous accepted event on that line.

ISR Behaviour

Interrupt | Action
INT0 - Emergency | Sets emergency_mode = 1; red LED + buzzer ON; counting locked
INT1 - Event | Increments event_count only if emergency_mode == 0
INT2 - Recovery / Reset | Returns to normal if in emergency; resets count if already normal

CT 321 PBL 07 - Group 7 - ATmega32 External Interrupt Event Counter System

6

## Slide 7

Firmware Structure

Event-driven design: Main loop + Interrupt Service Routines

Main Program

• Initializes GPIO (LEDs, buzzer), Timer0, USART, and external interrupts.
• Enables global interrupts and continuously updates LED / buzzer outputs based on current state.
• Prints status (mode + event count) over UART on every event and on a periodic heartbeat.

Interrupt Service Routines

• ISR(INT0_vect) - emergency stop: enters emergency mode immediately.
• ISR(INT1_vect) - event counter: increments count only in normal mode.
• ISR(INT2_vect) - recovery / reset: exits emergency mode, or resets count in normal mode.
• ISR(TIMER0_COMP_vect) - 1 ms system tick used for debounce timing.

CT 321 PBL 07 - Group 7 - ATmega32 External Interrupt Event Counter System

7

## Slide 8

KiCad Schematic Design


CT 321 PBL 07 - Group 7 - ATmega32 External Interrupt Event Counter System

8

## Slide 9

KiCad PCB Layout

Routed PCB - ERC and DRC passed with zero errors


CT 321 PBL 07 - Group 7 - ATmega32 External Interrupt Event Counter System

9

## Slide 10

PCB 3D View


CT 321 PBL 07 - Group 7 - ATmega32 External Interrupt Event Counter System

10

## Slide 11

SimulIDE Simulation - Normal Mode & Emergency Stop


Normal startup - Green LED ON, count 0

CT 321 PBL 07 - Group 7 - ATmega32 External Interrupt Event Counter System


Emergency stop - Red LED + buzzer ON

11

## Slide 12

SimulIDE Simulation - Counting Lockout & Recovery


Event press during emergency - count does not change

CT 321 PBL 07 - Group 7 - ATmega32 External Interrupt Event Counter System


Recovery - returns to normal mode, count preserved

12

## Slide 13

Test Results Summary

All 7 functional tests executed in SimulIDE - 8 MHz, UART 9600 8N1

# | Test Case | Result

1 | Normal startup | PASS
2 | Single event pulse | PASS
3 | Multiple event pulses | PASS
4 | Emergency stop | PASS
5 | Event during emergency (lockout) | PASS
6 | Recovery mode | PASS
7 | Reset in normal mode | PASS

CT 321 PBL 07 - Group 7 - ATmega32 External Interrupt Event Counter System

13

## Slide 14

Conclusion

• Successfully implemented an interrupt-driven emergency stop and event counter using INT0, INT1, and INT2.
• Demonstrated correct event-driven behaviour: immediate emergency response, accurate event counting, and reliable recovery.
• Verified debounce logic prevents false triggering from mechanical switch noise.
• Validated the design end-to-end: KiCad schematic and PCB (zero ERC/DRC errors), AVR-GCC firmware, and SimulIDE simulation.
• Confirms that external interrupts are well suited for fast, reliable response to safety-critical events in embedded systems.

Thank You

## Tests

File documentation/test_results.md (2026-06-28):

# Test Results

The tests below were captured from the SimulIDE simulation using the final firmware HEX file `firmware/hex/emergency_event_counter.hex`. The screenshots are stored in `simulide/screenshots/`.

| No. | Test case | Expected output | Observed output | Evidence file | Result |
|---:|---|---|---|---|---|
| 1 | Normal startup | Green LED ON, red LED OFF, buzzer OFF, serial shows NORMAL mode with count 0. | The system starts in NORMAL mode and the serial terminal shows count 0. | `01_normal_startup.png` | PASS |
| 2 | Single event pulse | Pressing Event button once increments the event count to 1. | The serial terminal shows NORMAL mode with count 1. | `02_single_event_count.png` | PASS |
| 3 | Multiple event pulses | Repeated event pulses increase the count step by step. | The serial terminal shows the count increasing after multiple event button presses. | `03_multiple_event_count.png` | PASS |
| 4 | Emergency stop | Emergency button activates emergency mode; red LED and buzzer turn ON, normal counting stops. | The serial terminal shows EMERGENCY STOP mode while the red LED/buzzer state is visible. | `04_emergency_stop.png` | PASS |
| 5 | Event during emergency | Pressing Event during emergency must not increase the count. | The count remains unchanged while the system stays in EMERGENCY STOP mode. | `05_counting_lockout.png` | PASS |
| 6 | Recovery mode | Pressing Recovery while in emergency returns system to NORMAL mode and preserves the current count. | The serial terminal returns to NORMAL mode and keeps the previous count. | `06_recovery_mode.png` | PASS |
| 7 | Reset in normal mode | Pressing Recovery/Reset again in normal mode resets the event count to 0. | The serial terminal shows NORMAL mode with count 0. | `07_reset_normal_mode.png` | PASS |

## Simulation evidence

- Screenshots folder: `simulide/screenshots/`
- Contact sheet: `simulide/screenshots/screenshots_contact_sheet.jpg`
- HEX file used: `firmware/hex/emergency_event_counter.hex`
- MCU frequency used in SimulIDE: 8 MHz
- Serial terminal setting: 9600 baud, 8 data bits, 1 stop bit

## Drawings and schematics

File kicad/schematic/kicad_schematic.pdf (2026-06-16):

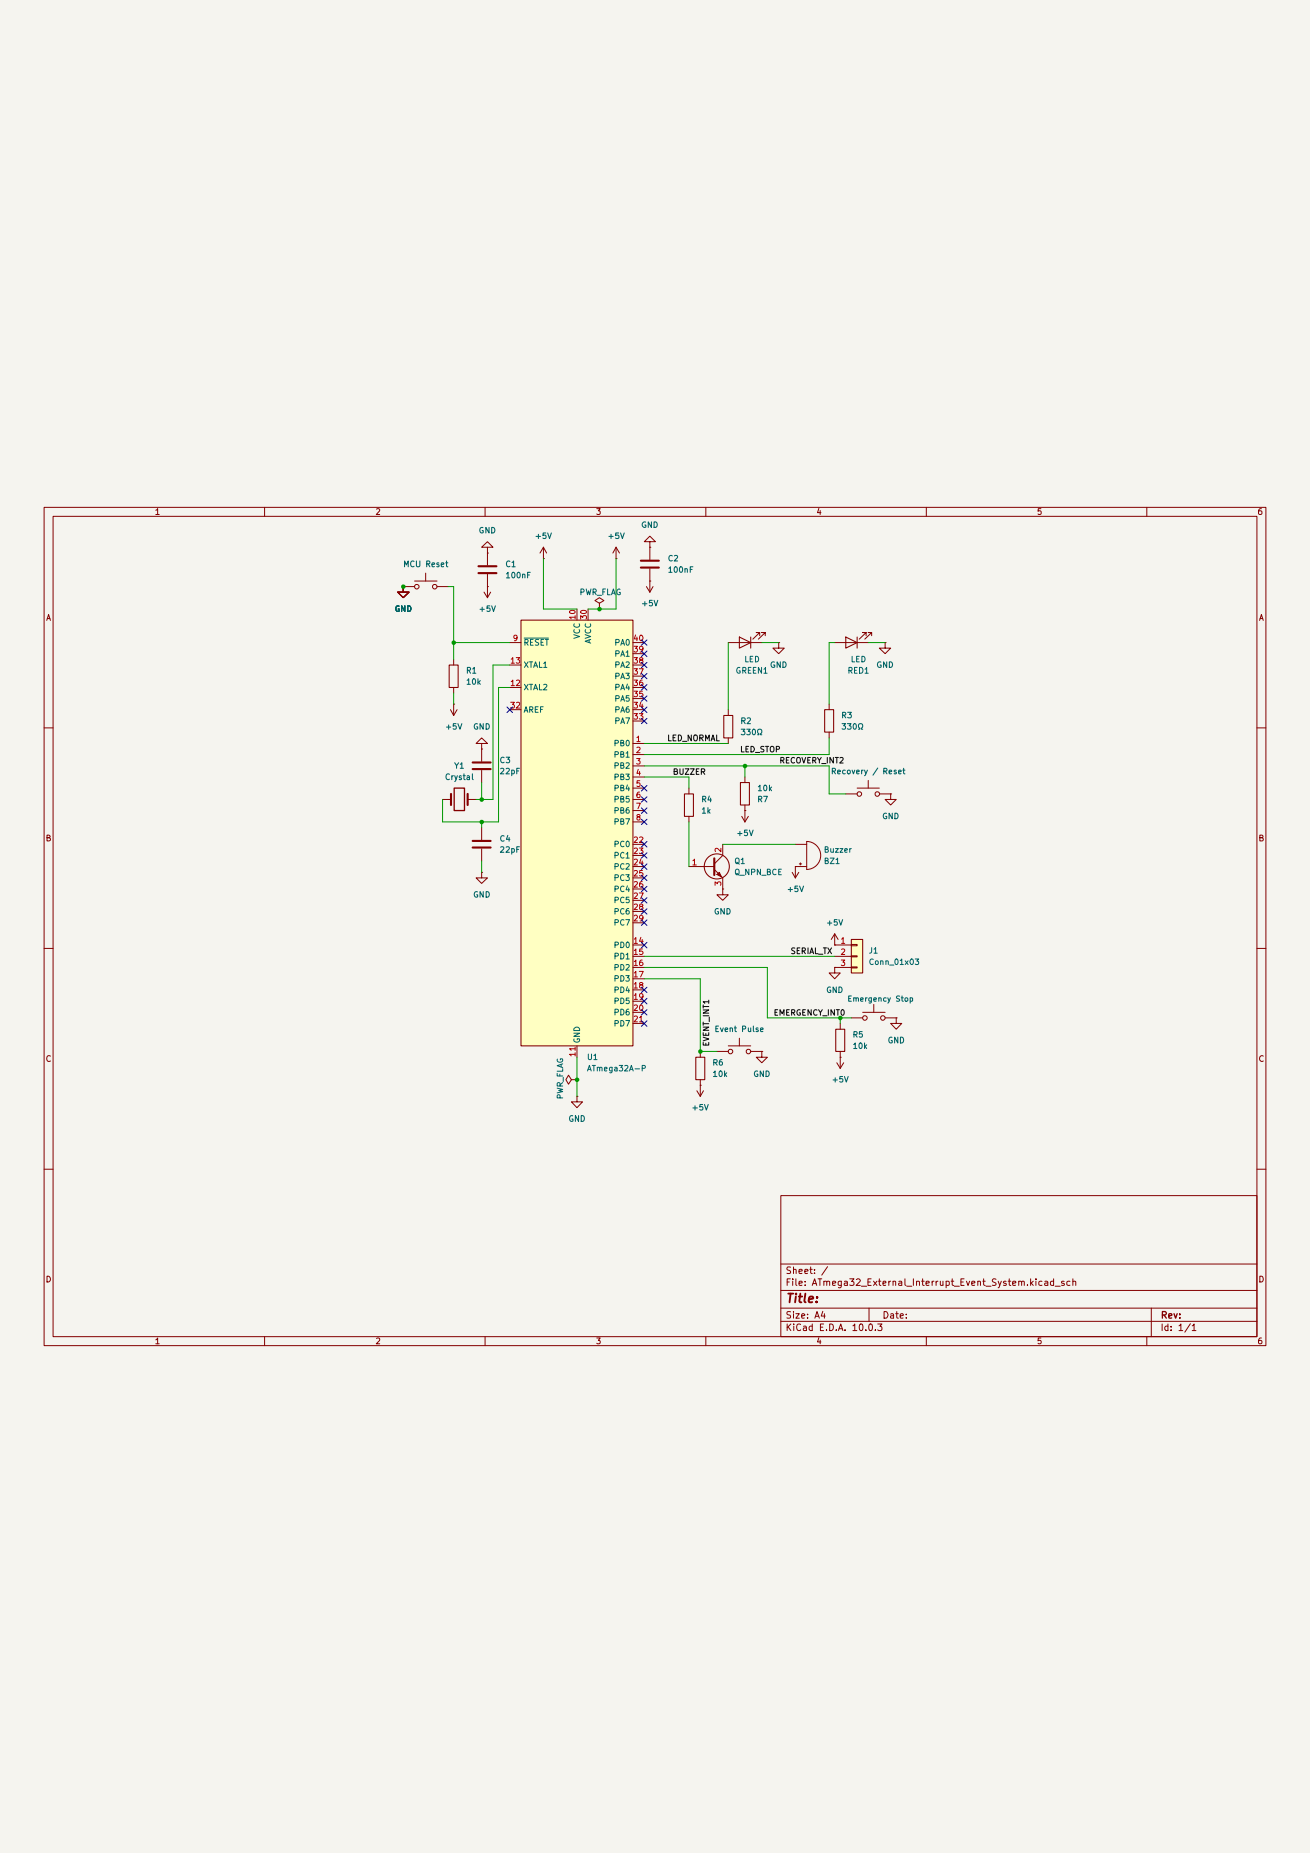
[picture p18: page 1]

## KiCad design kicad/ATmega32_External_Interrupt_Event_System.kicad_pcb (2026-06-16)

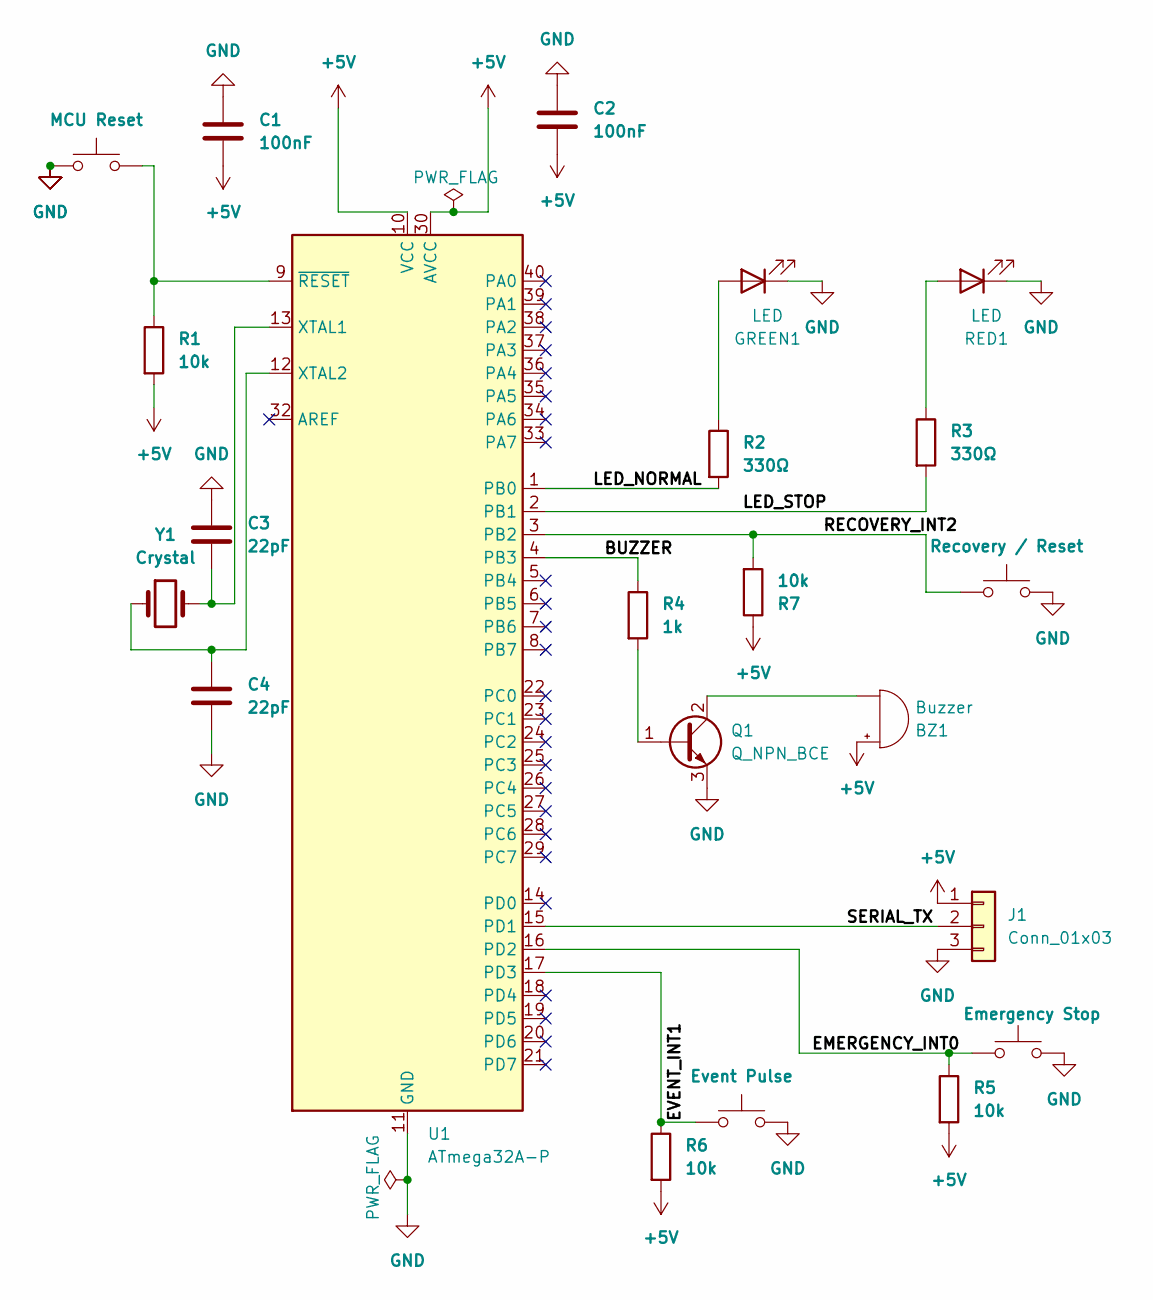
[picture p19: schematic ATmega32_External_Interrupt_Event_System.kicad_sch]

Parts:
BZ1: Buzzer; Buzzer_12x9.5RM7.6
C1, C2: 100nF; C_Disc_D5.0mm_W2.5mm_P5.00mm
C3, C4: 22pF; C_Disc_D5.0mm_W2.5mm_P5.00mm
EventPulse1: Event Pulse; SW_PUSH_6mm
GREEN1: LED; LED_D5.0mm
J1: Conn_01x03; PinHeader_1x03_P2.54mm_Vertical
MCU-Reset1: MCU Reset; SW_PUSH_6mm
Q1: Q_NPN_BCE; TO-92_Inline
R1, R5, R6, R7: 10k; R_Axial_DIN0207_L6.3mm_D2.5mm_P7.62mm_Horizontal
R2, R3: 330Ω; R_Axial_DIN0207_L6.3mm_D2.5mm_P7.62mm_Horizontal
R4: 1k; R_Axial_DIN0207_L6.3mm_D2.5mm_P7.62mm_Horizontal
RED1: LED; LED_D5.0mm
SW1: Emergency Stop; SW_PUSH_6mm
SW3: Recovery / Reset; SW_PUSH_6mm
U1: ATmega32A-P; DIP-40_W15.24mm
Y1: Crystal; Crystal_HC49-4H_Vertical

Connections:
+5V: BZ1.1 (+), C1.2, C2.2, J1.1, R1.2, R5.2, R6.2, R7.1, U1.10 (VCC), U1.30 (AVCC)
/ EVENT_INT1: EventPulse1.1, R6.1, U1.17 (PD3)
/BUZZER: R4.1, U1.4 (PB3)
/EMERGENCY_INT0: R5.1, SW1.1, U1.16 (PD2)
/LED_NORMAL: R2.2, U1.1 (PB0)
/LED_STOP: R3.2, U1.2 (PB1)
/RECOVERY_INT2: R7.2, SW3.1, U1.3 (PB2)
/SERIAL_TX: J1.2, U1.15 (PD1)
GND: C1.1, C2.1, C3.1, C4.2, EventPulse1.2, GREEN1.1 (K), J1.3, MCU-Reset1.1, Q1.3 (E), RED1.1 (K), SW1.2, SW3.2, U1.11 (GND), U1.31 (GND); also elsewhere on the board
unnamed: BZ1.2 (-), Q1.2 (C)
unnamed 10: GREEN1.2 (A), R2.1; also elsewhere on the board
unnamed: Q1.1 (B), R4.2
unnamed: R3.1, RED1.2 (A)
unnamed: C3.2, U1.13 (XTAL1), Y1.2
unnamed: C4.1, U1.12 (XTAL2), Y1.1
unnamed: MCU-Reset1.2, R1.1, U1.9 (~RESET)

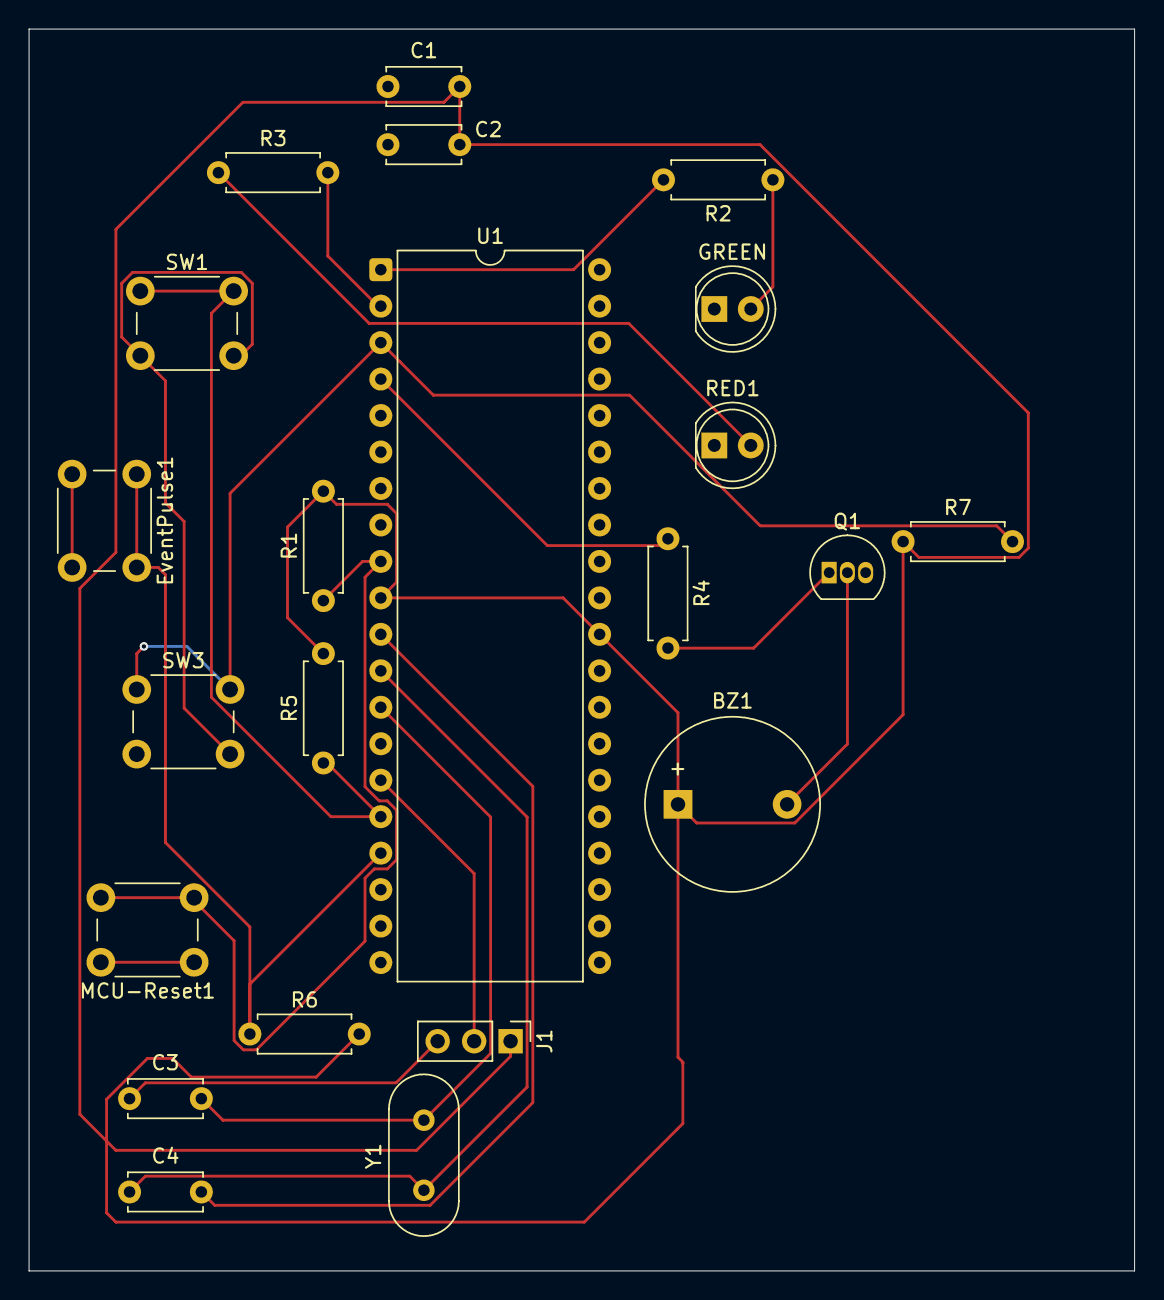
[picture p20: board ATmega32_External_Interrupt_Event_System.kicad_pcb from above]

Board: 2 copper layers, 77.0 x 86.5 mm, 22 parts (0 on the bottom side), 16 nets.

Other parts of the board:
GREEN: LED; LED_D5.0mm

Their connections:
GND: GREEN.1 (K); also elsewhere on the board
unnamed 10: GREEN.2 (A); also elsewhere on the board

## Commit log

2026-06-14 Created ATmega32 external interrupt event system project
    - Initialised repository structure for CT 321 PBL 07 assignment
    - Added project README with hardware list, pin table, build instructions,
    SimulIDE guide, test procedure, folder map, and submission status
    - Added .gitignore excluding *.elf, *.o, *.d, build/, dist/, .cache/
2026-06-14 Improved firmware for SimulIDE testing
    - update_outputs() now called every main loop iteration (not only on events)
    so LEDs and buzzer respond immediately when simulation starts
    - Added 1000 ms heartbeat: serial status printed every second even with
    no button activity, confirming the simulation is running
    - Added "System started" startup banner
    - Initial status line printed immediately before entering the main loop
    - Forced normal startup state (green ON, red OFF, buzzer OFF) before loop
    - All interrupts, debounce logic, and pin mapping unchanged
    - Rebuilt: Program 1403 bytes (4.3% flash), Data 80 bytes (3.9% SRAM)
2026-06-14 Restore final assignment firmware
    - main.c confirmed as assignment firmware (heartbeat + interrupt version)
    - emergency_event_counter.hex rebuilt from assignment main.c
    Program: 1403 bytes (4.3%), Data: 80 bytes (3.9%)
    - Added main_assignment_backup.c as a reference copy of assignment firmware
    - Added diagnostic_test.hex (simple blink/UART test used to verify SimulIDE)
2026-06-16 Final CT321 Group 7 submission package
    [ATmega32_External_Interrupt_Event_System-B_Cu.gbr, ATmega32_External_Interrupt_Event_System-B_Mask.gbr, ATmega32_External_Interrupt_Event_System-B_Silkscreen.g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]
2026-06-17 Add KiCad PCB 3D view images and embed circuit images in README
2026-06-28 Align project structure with assignment spec and remove redundant files
    [ATmega32_External_Interrupt_Event_System.kicad_pcb, ATmega32_External_Interrupt_Event_System.kicad_sch]
2026-06-28 Add PowerPoint presentation for CT321 Group 7 project
